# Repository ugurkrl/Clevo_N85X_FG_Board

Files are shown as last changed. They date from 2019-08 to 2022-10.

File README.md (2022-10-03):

# Clevo_N85X_FG_Board
Archived because i no longer have any Clevo laptop.
But this design works fine. Just tie FUSE pin to ground. Also dont forget to switch order of SDA and SCL pins !
I used this design longer than 2 years and i had no stability issues. Just make sure your BQ40z50 or 4050 settings are OK

BQ40z50/BQ4050 Fuel Gauge board for Clevo N850/5/7(Monster A5 V9) notebook computers.

**Issues**
1. Fix reverted SDA SCL 
1. bypass fuse pin



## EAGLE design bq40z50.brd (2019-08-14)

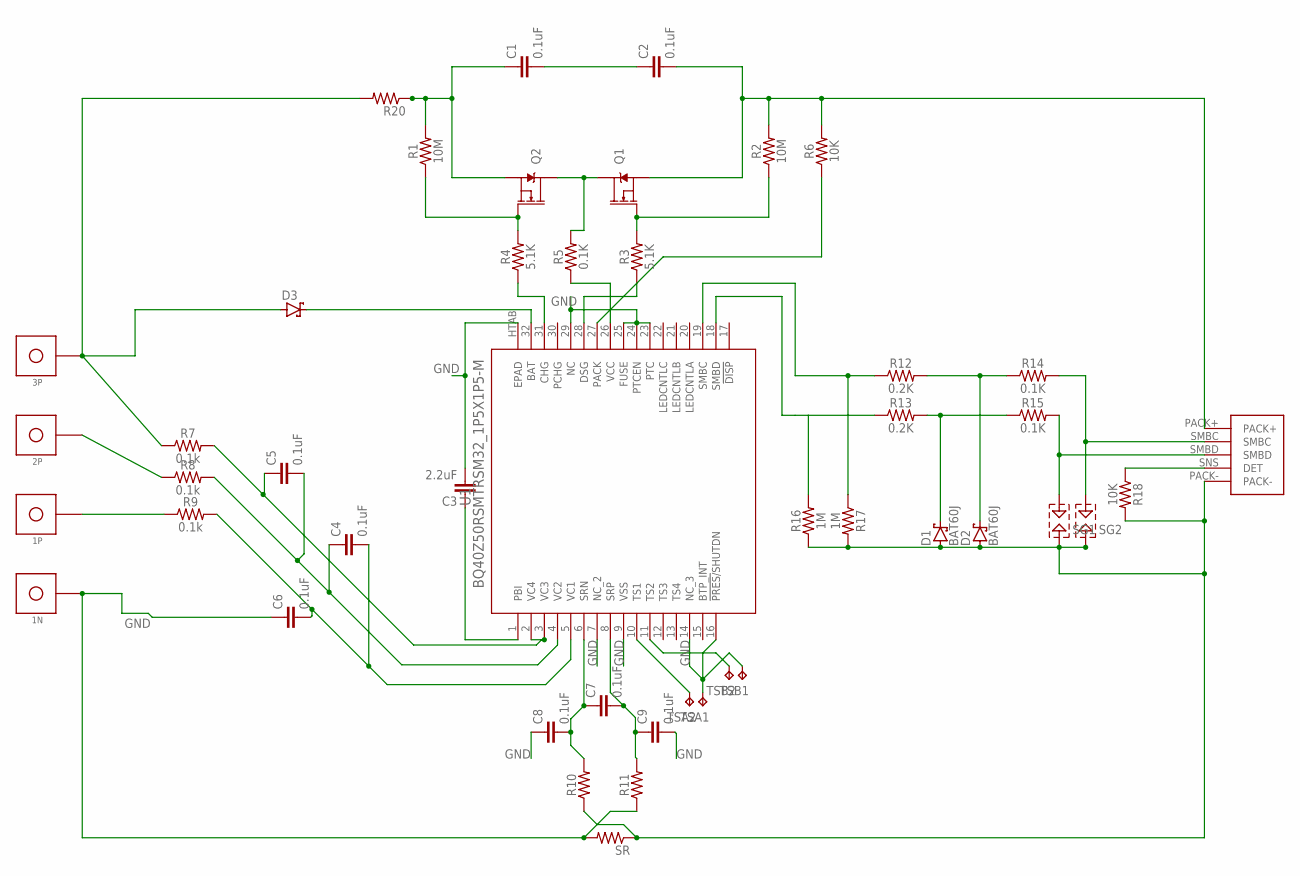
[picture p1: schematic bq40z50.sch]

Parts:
1N, 1P, 2P, 3P: BAT_TAB; BATT_TAB
C1, C2, C4, C5, C6, C7, C8, C9: 0.1uF; 0402
C3: 2.2uF; 0402
D1, D2, D3: BAT60J; SOD323_ST
Q1, Q2: 6.5A/30V/38mΩ; SO08
R1, R2: 10M; 0402
R3, R4: 5.1K; 0402
R5, R14, R15: 0.1K; 0402
R6, R18: 10K; 0402
R7, R8, R9: 0.1k; 0402
R10, R11: 0402
R12, R13: 0.2K; 0402
R16, R17: 1M; 0402
R20: R-US_R2512; R2512
SG1, SG2: SPARK-GAP-8
SR: R-US_R2512; R2512
TSA1, TSA2: TPTP18R; TP18R
TSB1, TSB2: TPTP18R; TP18R
U1: BQ40Z50RSMTRSM32_1P5X1P5-M; RSM32_1P5X1P5-M
U$1: N857HK1_FG; N850BAT

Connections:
GND: 1N.P$1, C3.2, C6.1, C8.1, C9.2, R11.1, SR.2, TSA1.TP, TSB1.TP, U1.7 (NC_2), U1.9 (VSS), U1.14 (NC_3), U1.16 (!PRES/!SHUTDN), U1.23 (PTC), U1.24 (PTCEN), U1.25 (FUSE), U1.29 (NC), U1.HTAB (EPAD)
unnamed: Q2.4 (G), R1.1, R4.2
unnamed: 3P.P$1, D3.A, R7.1, R20.2
unnamed: D1.A, D2.A, R10.1, R16.1, R17.2, R18.2, SG1.2, SG2.2, SR.1, U$1.PACK-
unnamed: C1.1, Q2.1 (S), Q2.2 (S), Q2.3 (S), R1.2, R20.1
unnamed: C1.2, C2.1
unnamed: C2.2, Q1.1 (S), Q1.2 (S), Q1.3 (S), R2.2, R6.2, U$1.PACK+
unnamed: Q1.5 (D), Q1.6 (D), Q1.7 (D), Q1.8 (D), Q2.5 (D), Q2.6 (D), Q2.7 (D), Q2.8 (D), R5.2
unnamed: Q1.4 (G), R2.1, R3.2
unnamed: R4.1, U1.31 (CHG)
unnamed: R3.1, U1.28 (DSG)
unnamed: R5.1, U1.26 (VCC)
unnamed: R6.1, U1.27 (PACK)
unnamed: D3.C, U1.32 (BAT)
unnamed: C3.1, U1.1 (PBI)
unnamed: C5.1, R7.2, U1.2 (VC4), U1.3 (VC3)
unnamed: 2P.P$1, R8.1
unnamed: 1P.P$1, R9.1
unnamed: C7.2, C9.1, R11.2, U1.8 (SRP)
unnamed: C4.1, C5.2, R8.2, U1.4 (VC2)
unnamed: C4.2, C6.2, R9.2, U1.5 (VC1)
unnamed: C7.1, C8.2, R10.2, U1.6 (SRN)
unnamed: TSA2.TP, U1.10 (TS1)
unnamed: TSB2.TP, U1.11 (TS2)
unnamed: R13.1, R16.2, U1.18 (SMBD)
unnamed: R12.1, R17.1, U1.19 (SMBC)
unnamed: D1.C, R13.2, R15.1
unnamed: D2.C, R12.2, R14.1
unnamed: R15.2, SG1.1, U$1.SMBD
unnamed: R14.2, SG2.1, U$1.SMBC
unnamed: R18.1, U$1.SNS (DET)

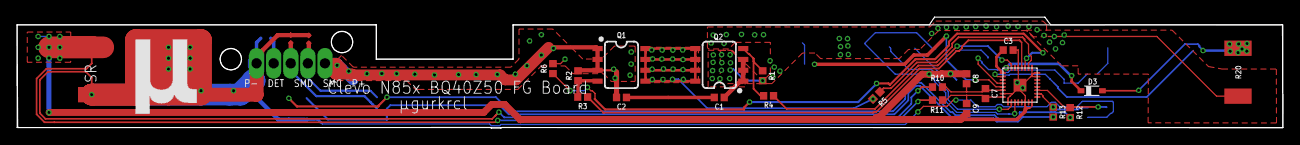
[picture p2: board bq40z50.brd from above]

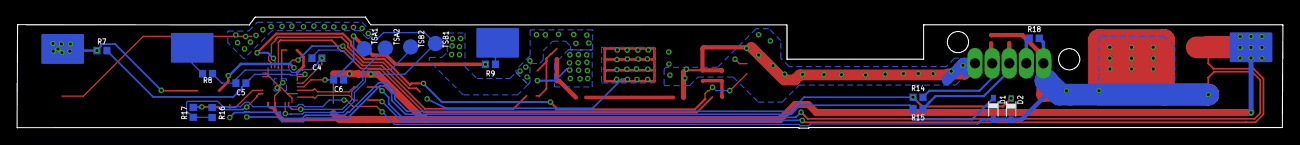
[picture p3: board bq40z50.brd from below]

Board: 2 copper layers, 148.0 x 13.0 mm, 46 parts (21 on the bottom side), 31 nets.

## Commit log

2019-08-14 schematic : fix reversed SMBC SMBD lines
    [bq40z50.sch]
2019-08-14 schematic : connect FUSE to GND (otherwise 40z50 doesn't enables FETs)
    [bq40z50.sch]
2019-08-14 schematic : spark gap mod
    [bq40z50.sch]
2019-08-14 board : apply schematic changes
    [bq40z50.brd]
2019-08-14 clean gerber files
    [bq40z50.GBL, bq40z50.GBO, bq40z50.GBP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]

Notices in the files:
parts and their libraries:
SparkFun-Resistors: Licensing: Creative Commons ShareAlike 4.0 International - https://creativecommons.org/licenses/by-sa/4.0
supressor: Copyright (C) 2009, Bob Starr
